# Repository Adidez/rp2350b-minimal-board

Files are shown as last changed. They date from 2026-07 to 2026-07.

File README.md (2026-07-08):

# RP2350B Minimal Board — AI-Assisted, Gate-Verified KiCad Project

A Raspberry Pi **RP2350B (QFN-80)** minimal development board, taken from the official reference
design to a **fab-ready, evidence-verified state** by a gated, evidence-first hardware pipeline
with a human decision at every gate.

| | |
|---|---|
| MCU | RP2350B, QFN-80 10×10 mm (order **A4 stepping only** — E9 erratum fixed in A4) |
| Board | 52.6 × 72.1 mm, 2-layer, all 48 GPIOs broken out (8 ADC-capable) |
| Design state | Schematic **ERC: 0 errors** · PCB **DRC: 0 errors**, 73/73 nets connected |
| EDA | KiCad 10.0.4 (design migrated from the official KiCad 7 files, equivalence-proven) |

**Top view** — [checks/pcb_top.png](checks/pcb_top.png) · **Bottom** — [checks/pcb_bottom.png](checks/pcb_bottom.png) · **Schematic PDF** — [checks/schematic_review.pdf](checks/schematic_review.pdf)

## Open the design in KiCad

Two ways:
1. **No git needed**: download [RP2350B_minimal_kicad_project.zip](RP2350B_minimal_kicad_project.zip)
   (or the repo ZIP via *Code ▾ → Download ZIP*), unzip, then double-click
   `design/RP2350_80QFN_minimal.kicad_pro`.
2. `git clone https://github.com/Adidez/rp2350b-minimal-board && open design/RP2350_80QFN_minimal.kicad_pro`

Requires **KiCad 9 or 10** (files are v10 format; project-local symbol + footprint libraries and
the STEP model are included, so it opens fully self-contained — no library setup needed).

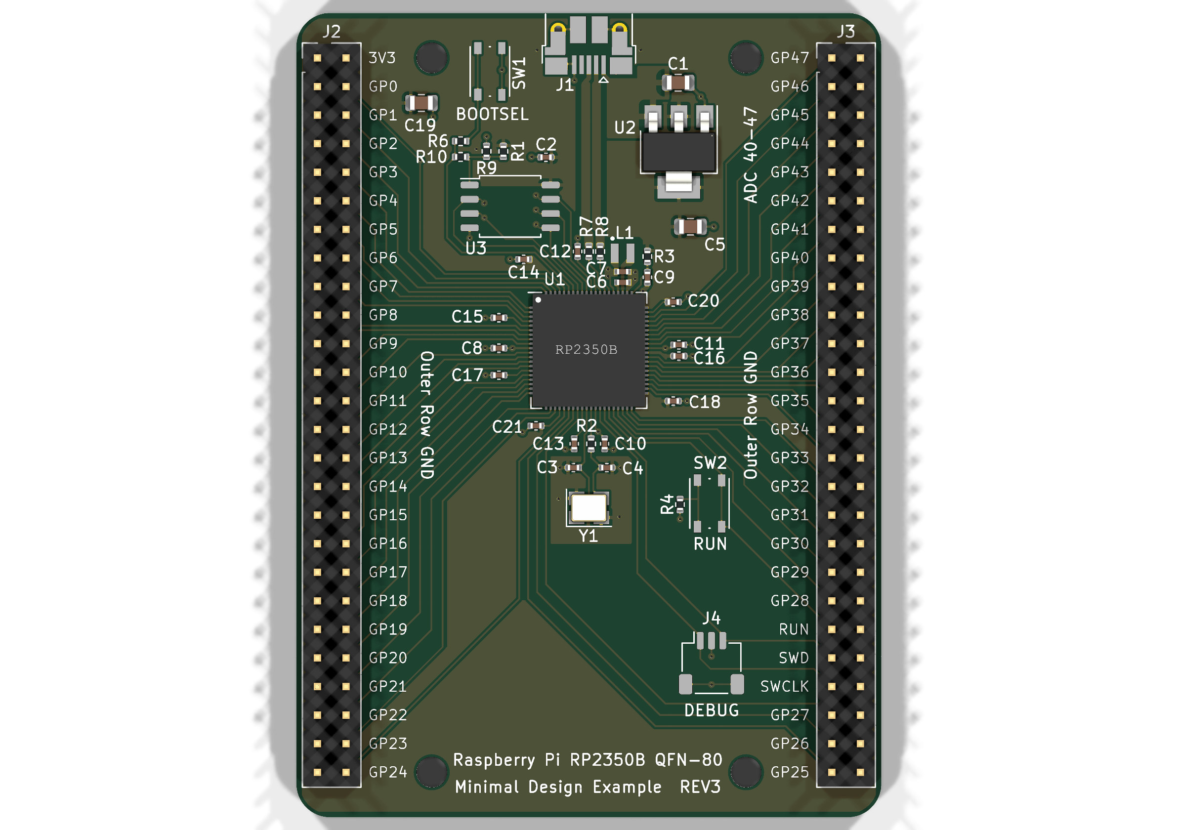
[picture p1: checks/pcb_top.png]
Top render


## What was actually done (the story)

1. **Stage 0 — Baseline.** Copied the official RP2350B minimal reference (KiCad 7) and migrated
   it under KiCad 10: installed global library tables (117 of 193 findings were phantom config
   noise), added the two missing `PWR_FLAG` declarations on the internal-VREG rails
   (`+1V1`, `VREG_AVDD`) that took ERC from 2 errors → 0, and re-linked a footprint KiCad 10
   renamed. Every schematic edit was proven by **netlist equivalence** — 75/75 nets,
   membership byte-identical.
2. **Stage 1 — Sourcing.** All 39 fitted parts got `MPN` + `LCSC` properties (hidden fields —
   the drawing stays clean) and a per-part datasheet corpus. Live-stock-checked ordering table:
   [checks/G1_gate_report.md](checks/G1_gate_report.md). One engineered substitution
   (Würth button → ALPS SKRPACE010, land-pattern-verified). 9 of 17 lines are JLCPCB Basic tier.
3. **Stage 2/3 — Layout verification.** The official routing was independently re-verified under
   modern checkers: 0 electrical DRC findings, full connectivity (511 segments / 48 vias /
   332 pads), USB pair geometry sound for full-speed, solid bottom GND plane. A false-positive
   severity policy from the KiCad-7 project file was fixed at root cause.
   Evidence: [checks/G3_prevalidation.md](checks/G3_prevalidation.md).
4. **Stage 4 — Fab package: DONE (Gate G4 PASS).** [fab/](fab/) holds the upload-ready set:
   [gerber zip](fab/RP2350B_minimal_gerbers.zip) (7 Protel-ext layers + PTH/NPTH drills,
   drill-count reconciled exactly against the design), [BOM](fab/bom_jlcpcb.csv) (17 lines,
   100% LCSC-resolved), [CPL](fab/cpl_jlcpcb.csv) (39 parts) and
   [ROTATION_NOTES.md](fab/ROTATION_NOTES.md). Release-gate evidence:
   [checks/G4_fab_release_gate.txt](checks/G4_fab_release_gate.txt).

Full audit trail: `git log` — every gate closes with its own commit and report in [checks/](checks/).

## Repository map

```
design/       The working KiCad project (schematic + routed PCB) — ERC/DRC clean
reference/    Official Raspberry Pi minimal design (untouched) + hardware design guide PDF
checks/       Gate reports + ERC/DRC JSON evidence + renders (the generated documents)
datasheets/   Per-MPN vendor datasheets (17) + manifest
fab/          JLCPCB-ready package: gerber zip, assembly BOM (LCSC), CPL, rotation notes
.claude/      The pipeline skill: stage gates, RP2350B design rules, toolchain quirks
```

## The design rules that matter (and that generic AI gets wrong)

- **A4 stepping only** (`RP2350B0A4`, LCSC C9900208890): A2 has erratum E9 (GPIO input-mode
  leakage ~120 µA, latches ~2.2 V). Verify at bring-up via `rp2350_chip_version()`.
- The RP2350 core regulator is a **switcher, not an LDO**: the 3.3 µH inductor
  (Abracon AOTA-B201610S3R3, **polarity dot**) is mandatory.
- `QSPI_SS` is the BOOTSEL strap and `QSPI SD1` selects the bootloader interface — neither may
  be loaded or biased at reset.
- Crystal is CL=10 pF (ABM8-272-T3) with tuned damping — don't substitute a 20 pF part without
  re-deriving load caps.
- Full list with sources: [.claude/skills/rp2350b-hardware-pipeline/references/rp2350b-design-rules.md](.claude/skills/rp2350b-hardware-pipeline/references/rp2350b-design-rules.md)

## Reproduce the verification yourself

```bash
KCLI=/Applications/KiCad/KiCad.app/Contents/MacOS/kicad-cli   # macOS bundle path
$KCLI sch erc --severity-all --output /tmp/erc.rpt design/RP2350_80QFN_minimal.kicad_sch   # → 0 errors
$KCLI pcb drc --severity-all --refill-zones --output /tmp/drc.rpt design/RP2350_80QFN_minimal.kicad_pcb  # → 0 errors
$KCLI pcb render --side top --output /tmp/top.png design/RP2350_80QFN_minimal.kicad_pcb
```

Expected residual warnings are documented (66 `endpoint_off_grid` + 6 `lib_symbol_mismatch` on
the schematic; 52 metadata findings on the PCB) — see the gate reports for the keep-rationale.

## Remaining path to a live board (human steps)

1. **Order at JLCPCB**: upload [fab/RP2350B_minimal_gerbers.zip](fab/RP2350B_minimal_gerbers.zip) +
   [BOM](fab/bom_jlcpcb.csv) + [CPL](fab/cpl_jlcpcb.csv). In the assembly preview, verify
   orientation of U1/U2/U3/J1/L1/Y1 against [checks/pcb_top.png](checks/pcb_top.png) — see
   [fab/ROTATION_NOTES.md](fab/ROTATION_NOTES.md). RP2350B **A4** (C9900208890) is a
   global-sourcing part — reserve early; re-verify all Extended-tier stock (table dated
   2026-07-07). Pick **Standard** assembly if J2/J3 headers should be machine-placed
   (Economic = SMD-only → hand-solder the headers).
2. **Bring-up**: 3V3 → 1V1 (proves VREG + inductor) → hold BOOTSEL, plug USB → mass-storage
   enumeration → flash a UF2 → confirm **A4** in silicon via `rp2350_chip_version()`.

## Attribution & licenses

- Base design: **Raspberry Pi Ltd** — "RP2350B QFN80 Minimal Design Example" from
  [Hardware design with RP2350](https://datasheets.raspberrypi.com/rp2350/hardware-design-with-rp2350.pdf)
  (© Raspberry Pi Ltd, redistributed with attribution; reference copy unmodified in `reference/`).
- Vendor datasheets in `datasheets/` remain the property of their respective manufacturers
  (Winbond, onsemi, Abracon, Samsung, UNI-ROYAL, ALPS, JST, Amphenol, XKB, Raspberry Pi).
- Verification tooling: [KiCad](https://kicad.org) 10.0.4 · [kicad-happy](https://github.com/aklofas/kicad-happy)
  (analysis) · [KiCadRoutingTools](https://github.com/drandyhaas/KiCadRoutingTools) (post-route checks).
- Pipeline definition: project-specific gated skill
  ([.claude/skills/rp2350b-hardware-pipeline](.claude/skills/rp2350b-hardware-pipeline)).

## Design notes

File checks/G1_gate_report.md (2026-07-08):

# Gate G1 — PASS (2026-07-07)

Schematic: design/RP2350_80QFN_minimal.kicad_sch @ 452c132.
Independent verify: ERC 0 errors (66 endpoint_off_grid + 6 lib_symbol_mismatch keep-set) ·
39 MPN + 39 LCSC properties · 17 datasheet PDFs + manifest (kicad-happy convention) ·
analyzer: 2 findings total = the known-benign RS-001 pair; DS-001 cleared; netlist membership
75/75 unchanged (agent-verified, s-expression compare).

## Ordering table (live stock 2026-07-07 — RE-VERIFY at order time)

| Refs | MPN | LCSC | Tier | Stock seen | Notes |
|---|---|---|---|---|---|
| C1,C5,C19 10u 0805 | CL21A106KAYNNNE | C15850 | Basic | 12.7M | |
| C2,C8,C11–C18,C20,C21 100n | CL05B104KO5NNNC | C1525 | Basic | 54M | |
| C3,C4 15p C0G | 0402CG150J500NT | C1548 | Basic | 882K | crystal loads |
| C6,C7,C9,C10 4.7u | CL05A475MP5NRNC | C23733 | Basic | 4.8M | |
| L1 3.3µH | AOTA-B201610S3R3-101-T | C42411119 | Extended | 22.5K | exact qualified part; POLARITY DOT |
| R2,R4,R6 1k | 0402WGF1001TCE | C11702 | Basic | 12.6M | |
| R3 33 | 0402WGF330JTCE | C25105 | Basic | 4.8M | |
| R7,R8 27 | 0402WGF270JTCE | C25100 | Extended | 273K | USB series; no Basic 27Ω exists |
| R10 0R | 0402WGF0000TCE | C17168 | Basic | 18.4M | |
| Y1 | ABM8-272-T3 | C20625731 | Extended | 15.7K | CL=10pF qualified |
| U1 | RP2350B **A4** | C9900208890 | Extended | 0 shelf — JLC global-sourcing, procured per order | **reserve early**; alt C42415655 rejected (stepping unverified) |
| U2 | NCP1117ST33T3G | C26537 | Extended | 14.2K | |
| U3 | W25Q128JVSIQ | C97521 | Basic | 110K | |
| J1 | 10103594-0001LF | C428495 | Extended | 7.8K | exact Amphenol |
| J2,J3 2×26 | X6521WV-2x26H-C60D30 | C725898 | Extended | **781** | watch stock |
| J4 | SM03B-SRSS-TB(LF)(SN) | C160403 | Extended | 4.5K | SWD |
| SW1,SW2 | **ALPS SKRPACE010** | C139797 | Extended | 156K | **SUBSTITUTION** for Würth 434133025816 (not carried): land pattern verified exact match (1.05×0.65 @ ±2.075/±1.075), same 4.2×3.2 J-bend; 2.55N vs 1.6N actuation |
| H1–H4 | — | — | — | — | mounting holes, no part |

DNF (excluded from order): C22, R1, R9, R11, R13, U4.

## Datasheet corrections made
- W25Q128JVSIQ: schematic's legacy URL pointed at the JV_DTR family doc — corrected to plain JV.
- NCP1117: onsemi direct blocked → LCSC CDN copy, manifest patched.

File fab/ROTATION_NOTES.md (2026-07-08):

# CPL Rotation Notes — JLCPCB upload preview (MANDATORY human check)

Generated with Stage 4 fab package (Gate G4), 2026-07-07.
Source: `fab/cpl_jlcpcb.csv` (kicad-cli pos export, front side, mm, rotations
normalized 0–360). **No rotation offsets were pre-applied.**

## Why no offsets were baked in

Per the kicad-happy `jlcpcb` skill guidance: JLCPCB's pick-and-place uses
different rotation conventions than KiCad for some footprint families, but
JLCPCB also maintains its own per-LCSC-part orientation database and its
order-review step renders every part on the board. Blindly adding the
"typical" offsets on top of that database risks double-rotation. This is our
**first assembly order** of this board — the skill's process is: verify in
the upload preview now, then record any corrections needed and apply them to
future CPL exports.

**At upload time: open the JLCPCB assembly preview and visually confirm pin-1
/ polarity of every part below against `checks/pcb_top.png` (approved 3D
render) before paying.**

## Parts to eyeball, with expected-offset hints (from the jlcpcb skill table)

| Ref | Package | CPL rotation | Skill's typical JLCPCB offset | What to check in preview |
|-----|---|---|---|---|
| U1 | QFN-80 (RP2350B) | 0.0 | QFN: +90° | Pin-1 dot top-left when text upright; 0.4 mm pitch — any rotation error is fatal |
| U2 | SOT-223 (NCP1117) | 270.0 | SOT-223: +180° | Tab (pin 2/Vout) toward board edge as in render |
| U3 | SOIC-8 (W25Q128JVS) | 0.0 | SOIC-8: +90° or +270° | Pin-1 dot orientation vs silkscreen dot |
| J1 | USB Micro-B (Amphenol 10103594-0001LF) | 180.0 | USB connectors: varies | Receptacle opening must face off-board edge |
| L1 | L_pol_2016 (AOTA-B201610S3R3-101-T) | 0.0 | not in table — **polarized inductor** | **POLARITY DOT** must match reference layout (G1 note); VREG switcher inductor |
| Y1 | Crystal 3225 4-pin (ABM8-272-T3) | 0.0 | not in table | Pin-1 corner vs footprint; 4-pad crystal shorts GND if rotated 90° |

Lower-risk but glance anyway: SW1/SW2 (270/90), J4 (JST SH, 0.0) — connector
keying visible in preview; passives are symmetric.

## Other CPL conventions

- Coordinates are KiCad pos-file convention (absolute board origin, Y
  negative-down); JLCPCB auto-aligns the CPL to the gerbers in its preview —
  if parts land off-board in the preview, use JLCPCB's "align" tools, do not
  hand-edit coordinates.
- J2/J3 (2×26 0.100" headers) are through-hole: they appear in BOM+CPL for
  Standard (THT-capable) assembly; delete both lines from BOM+CPL instead if
  ordering Economic/SMD-only and hand-soldering the headers.
- After this first order: record every correction JLCPCB's preview required
  into this file and pre-apply them in the next CPL export (skill guidance).

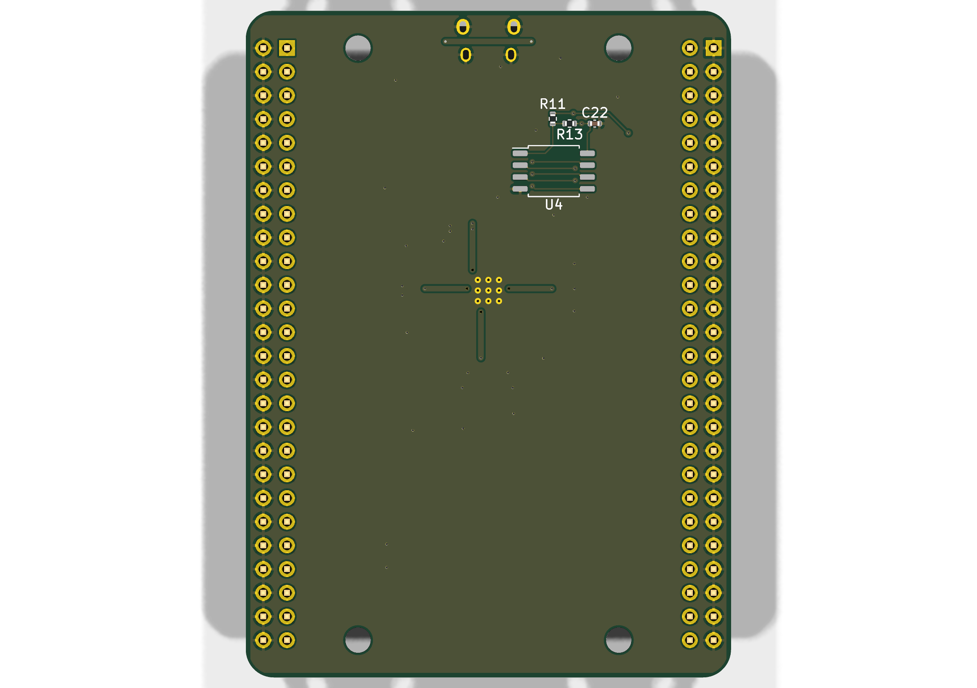
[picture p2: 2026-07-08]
checks/pcb_bottom.png

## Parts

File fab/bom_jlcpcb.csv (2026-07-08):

Comment | Designator | Footprint | LCSC Part #
10u | C1,C5,C19 | C_0805_2012Metric | C15850
100n | C2,C8,C11,C12,C13,C14,C15,C16,C17,C18,C20,C21 | C_0402_1005Metric | C1525
15p | C3,C4 | C_0402_1005Metric | C1548
4.7u | C6,C7,C9,C10 | C_0402_1005Metric | C23733
USB_B_Micro | J1 | USB_Micro-B_Amphenol_10103594-0001LF_Horizontal | C428495
Conn_02x26_Odd_Even | J2,J3 | PinHeader_2x26_P2.54mm_Vertical | C725898
SM03B-SRSS-TB | J4 | JST_SH_SM03B-SRSS-TB_1x03-1MP_P1.00mm_Horizontal | C160403
3.3u | L1 | L_pol_2016 | C42411119
1k | R2,R4,R6 | R_0402_1005Metric | C11702
33 | R3 | R_0402_1005Metric | C25105
27 | R7,R8 | R_0402_1005Metric | C25100
0 | R10 | R_0402_1005Metric | C17168
SW_Push | SW1,SW2 | SW_Push_1P1T_NO_Vertical_Wuerth_434133025816 | C139797
RP2350_80QFN | U1 | RP2350-QFN-80-1EP_10x10_P0.4mm_EP3.4x3.4mm_ThermalVias | C9900208890
NCP1117-3.3_SOT223 | U2 | SOT-223-3_TabPin2 | C26537
W25Q128JVS | U3 | SOIC-8_5.3x5.3mm_P1.27mm | C97521
ABM8-272-T3 | Y1 | Crystal_SMD_3225-4Pin_3.2x2.5mm | C20625731

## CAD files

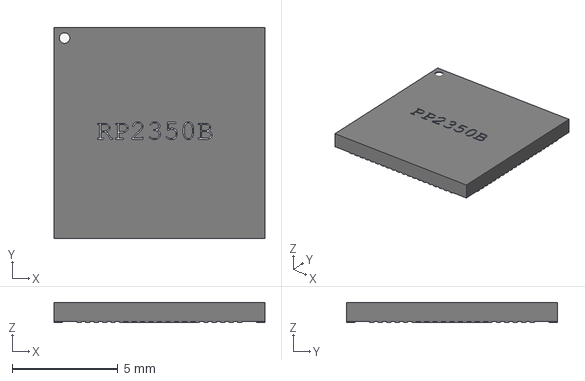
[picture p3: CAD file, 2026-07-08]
design/RP2350_QFN80.step
10.0 x 10.0 x 0.95 mm

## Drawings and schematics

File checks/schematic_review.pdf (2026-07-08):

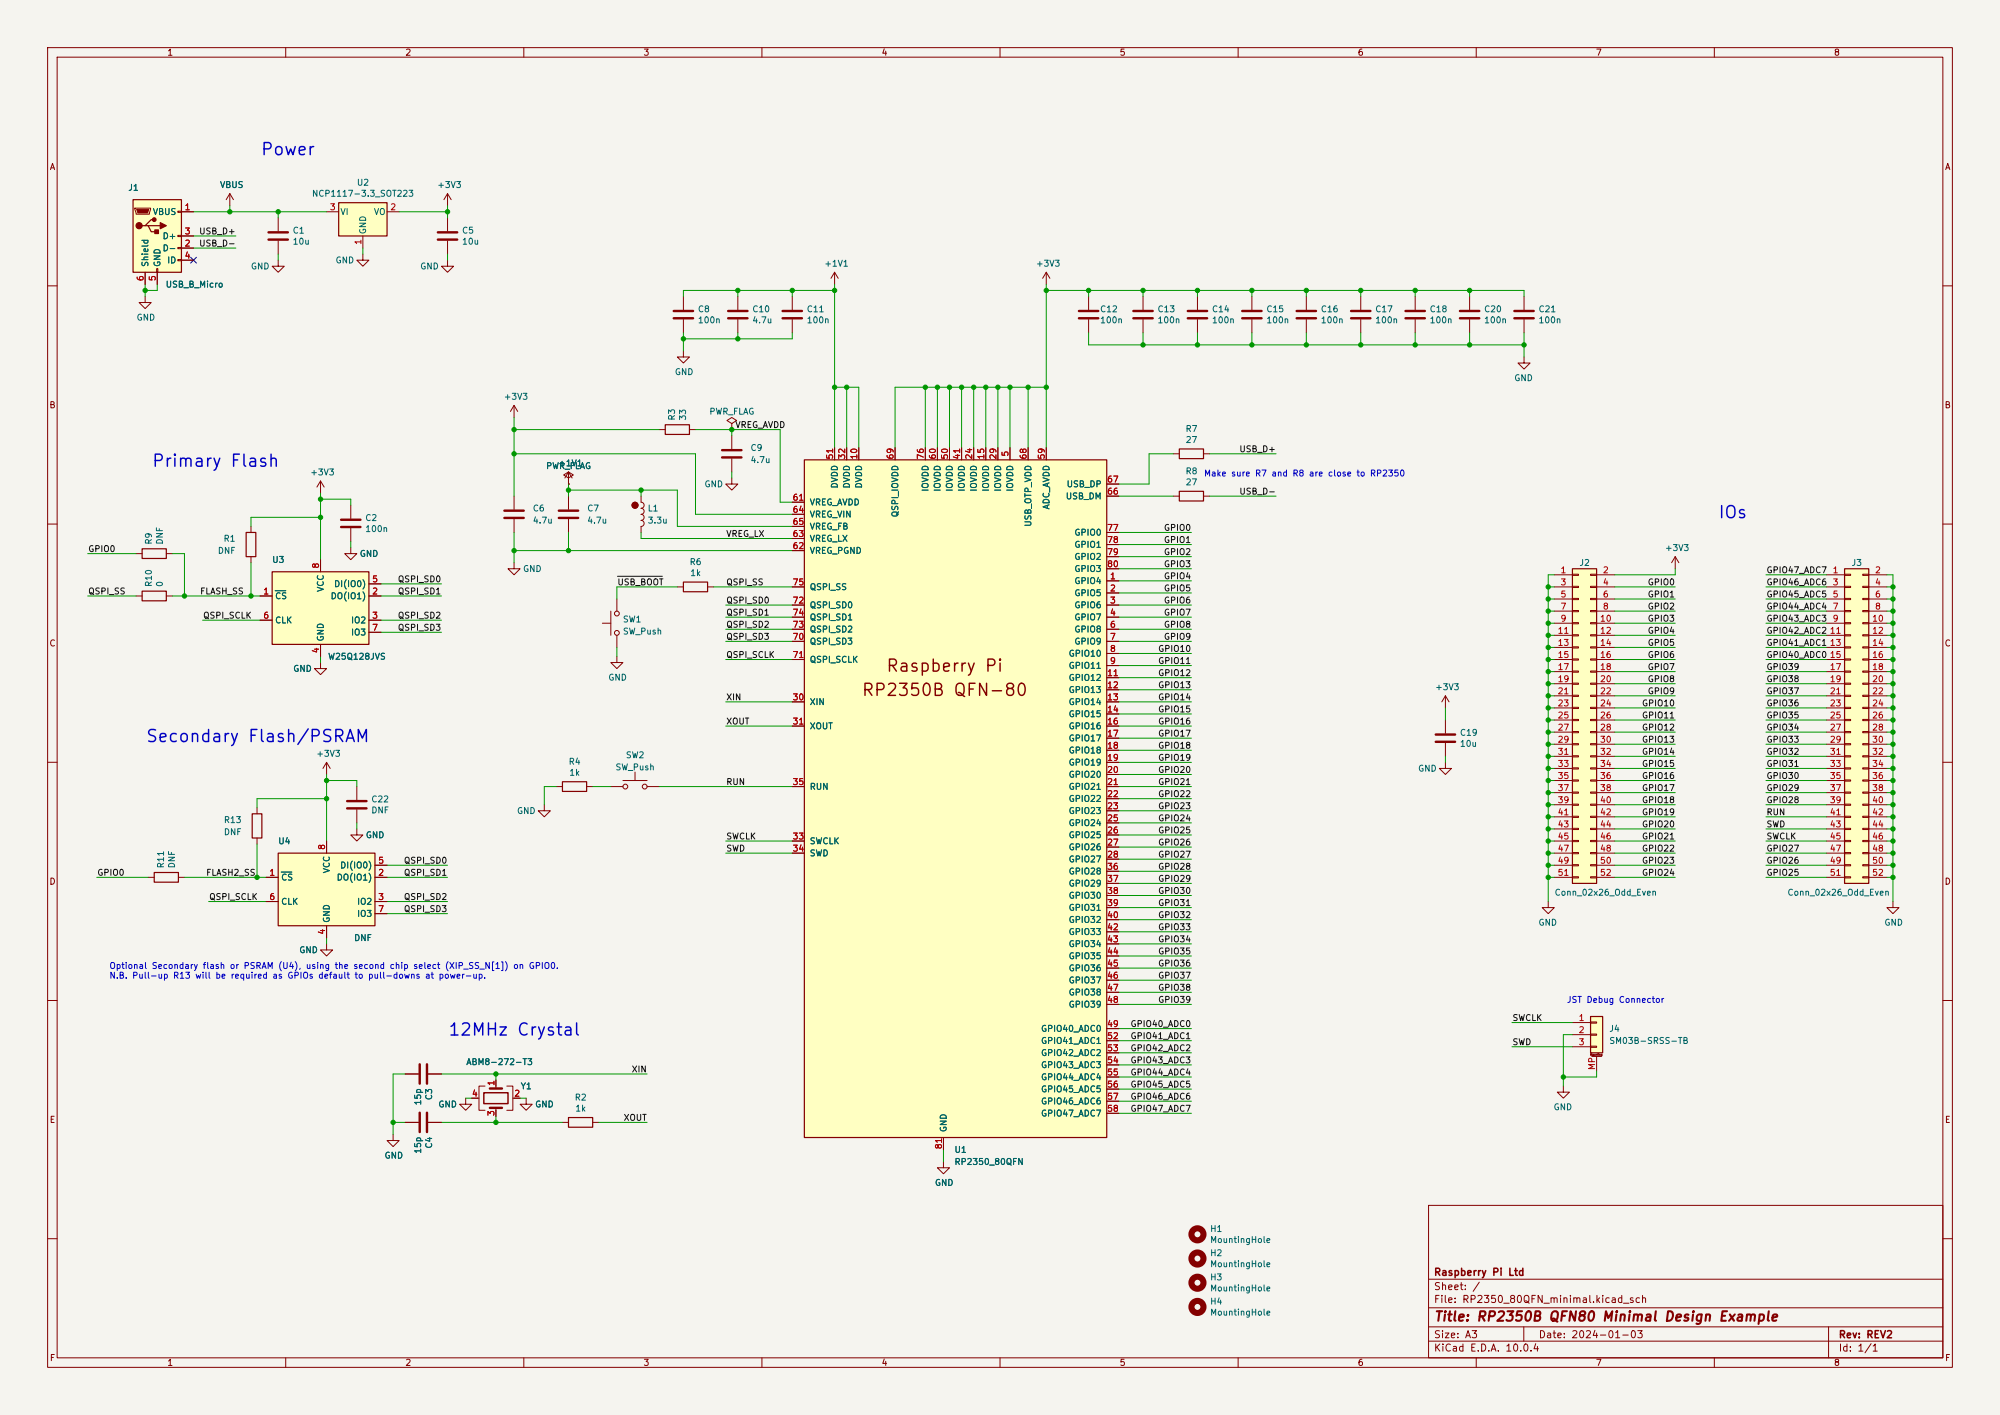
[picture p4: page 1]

5 GPIO8 6 GPIO9 7 GPIO10 8 GPIO11 9 DVDD 10 GPIO12 11 GPIO13 12 GPIO14 13 GPIO15 14 IOVDD 15 GPIO16 16 GPIO17 17 GPIO18 18 GPIO19 19 GPIO20 20 GPIO21 21 GPIO22 22 GPIO23 23 IOVDD 24 GPIO24 25 GPIO25 26 GPIO26 27 GPIO27 28 IOVDD 29

Make sure R7 and R8 are close to RP2350

Optional Secondary flash or PSRAM (U4), using the second chip select (XIP_SS_N[1]) on GPIO0. N.B. Pull-up R13 will be required as GPIOs default to pull-downs at power-up. Secondary Flash/PSRAM

8U4 DNF GND R11 DNF +3V3 GND

Raspberry Pi Ltd
Sheet: /
File: RP2350_80QFN_minimal.kicad_sch
Title: RP2350B QFN80 Minimal Design Example

Size: A3 | Rev: REV2 | F Date: 2024-01-03
KiCad E.D.A. 10.0.4 | Id: 1/1

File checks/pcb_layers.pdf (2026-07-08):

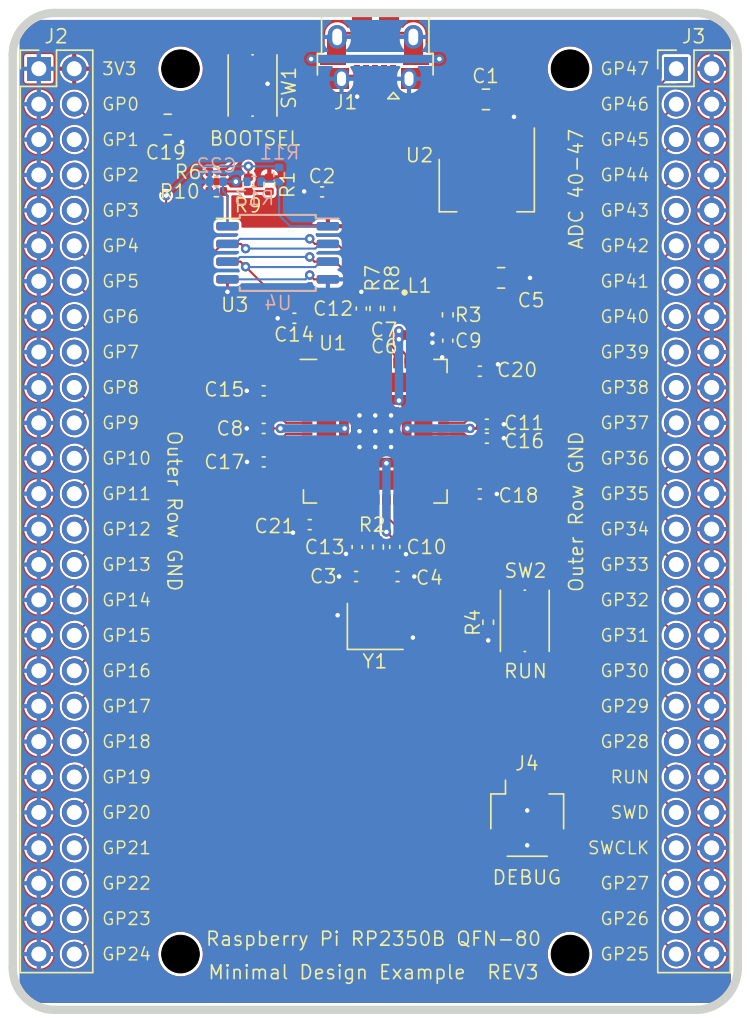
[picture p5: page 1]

DEBUG ADC 40-47 Outer Row GND Outer Row GND
GP27 GP26 GP25 BOOTSEL Raspberry Pi RP2350B QFN-80 Minimal Design Example REV3 RUN

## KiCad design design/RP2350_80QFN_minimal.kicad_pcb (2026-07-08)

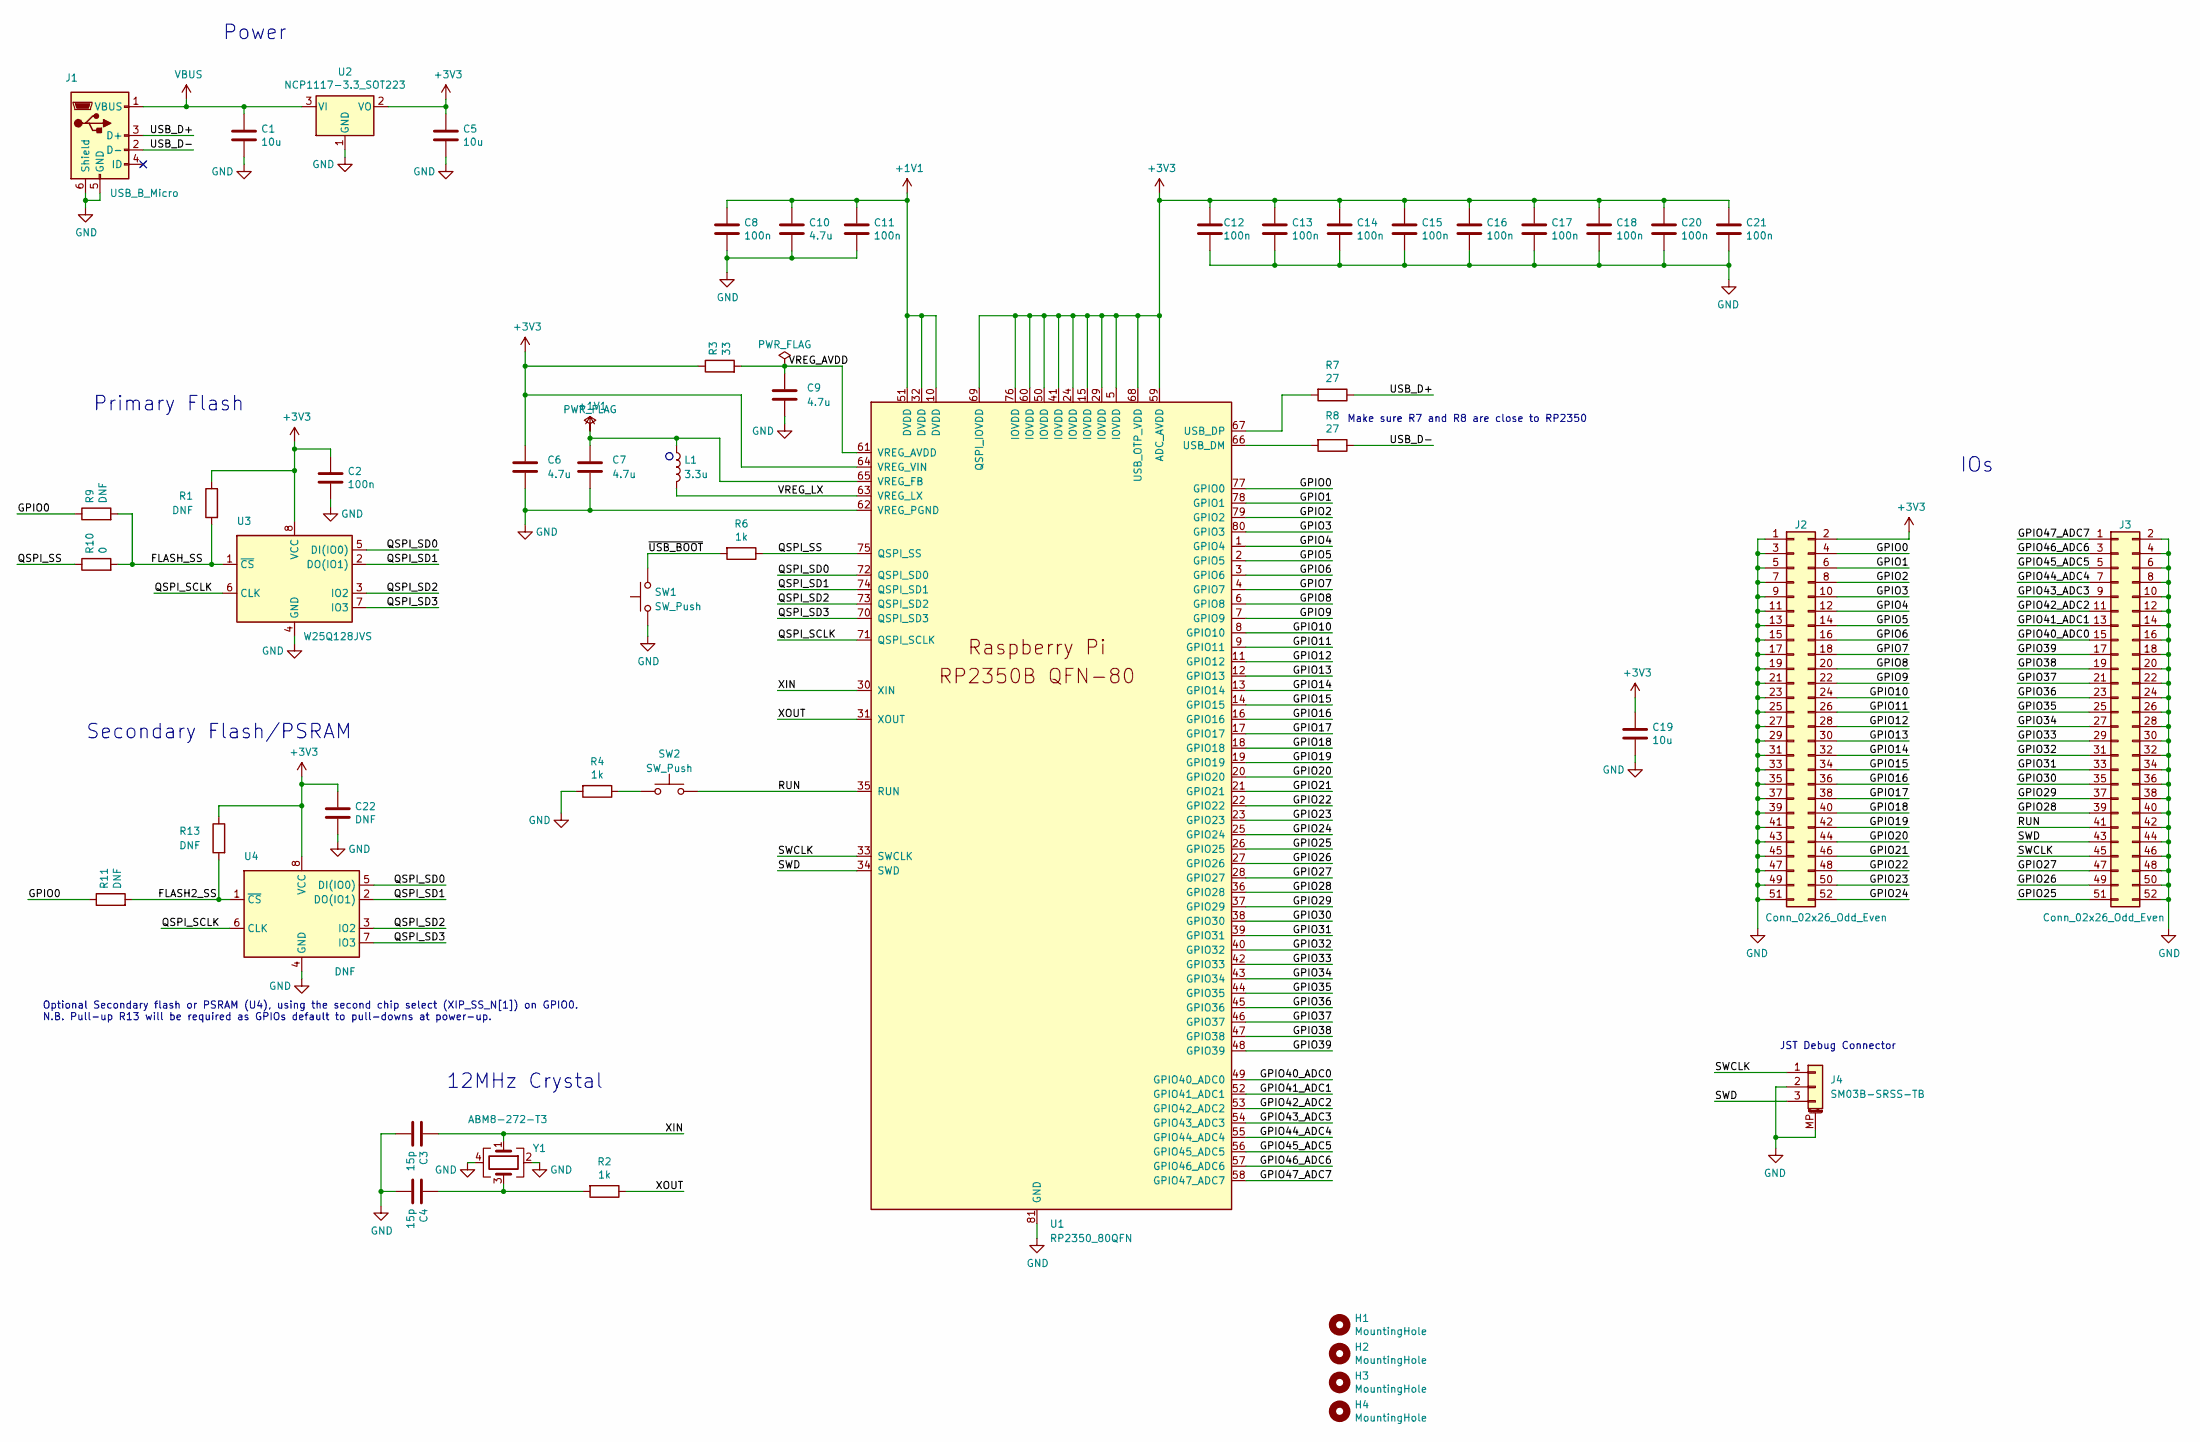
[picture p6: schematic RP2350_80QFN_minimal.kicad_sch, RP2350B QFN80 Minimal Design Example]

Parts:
C1, C5, C19: 10u; C_0805_2012Metric; MPN CL21A106KAYNNNE; LCSC C15850
C2, C8, C11, C12, C13, C14, C15, C16, C17, C18, C20, C21: 100n; C_0402_1005Metric; MPN CL05B104KO5NNNC; LCSC C1525
C3, C4: 15p; C_0402_1005Metric; MPN 0402CG150J500NT; LCSC C1548
C6, C7: 4.7u; C_0402_1005Metric_small_pads; MPN CL05A475MP5NRNC; LCSC C23733
C9, C10: 4.7u; C_0402_1005Metric; MPN CL05A475MP5NRNC; LCSC C23733
C22: DNF; C_0402_1005Metric
H1, H2, H3, H4: MountingHole; MountingHole_2.7mm_M2.5
J1: USB_B_Micro; USB_Micro-B_Amphenol_10103594-0001LF_Horizontal; MPN 10103594-0001LF; LCSC C428495
J2, J3: Conn_02x26_Odd_Even; PinHeader_2x26_P2.54mm_Vertical; MPN X6521WV-2x26H-C60D30; LCSC C725898
J4: SM03B-SRSS-TB; JST_SH_SM03B-SRSS-TB_1x03-1MP_P1.00mm_Horizontal; MPN SM03B-SRSS-TB(LF)(SN); LCSC C160403
L1: 3.3u; L_pol_2016; MPN AOTA-B201610S3R3-101-T; LCSC C42411119
R1, R9, R11, R13: DNF; R_0402_1005Metric
R2, R4, R6: 1k; R_0402_1005Metric; MPN 0402WGF1001TCE; LCSC C11702
R3: 33; R_0402_1005Metric; MPN 0402WGF330JTCE; LCSC C25105
R7, R8: 27; R_0402_1005Metric; MPN 0402WGF270JTCE; LCSC C25100
R10: 0; R_0402_1005Metric; MPN 0402WGF0000TCE; LCSC C17168
SW1, SW2: SW_Push; SW_Push_1P1T_NO_Vertical_Wuerth_434133025816; MPN SKRPACE010; LCSC C139797
U1: RP2350_80QFN; RP2350-QFN-80-1EP_10x10_P0.4mm_EP3.4x3.4mm_ThermalVias; MPN RP2350B A4; LCSC C9900208890
U2: NCP1117-3.3_SOT223; SOT-223-3_TabPin2; MPN NCP1117ST33T3G; LCSC C26537
U3: W25Q128JVS; SOIC-8_5.3x5.3mm_P1.27mm; MPN W25Q128JVSIQ; LCSC C97521
U4: DNF; SOIC-8_5.3x5.3mm_P1.27mm
Y1: ABM8-272-T3; Crystal_SMD_3225-4Pin_3.2x2.5mm; MPN ABM8-272-T3; LCSC C20625731

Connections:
+1V1: C7.1, C8.1, C10.1, C11.1, L1.1, U1.10 (DVDD), U1.32 (DVDD), U1.51 (DVDD), U1.65 (VREG_FB)
+3V3: C2.1, C5.1, C6.1, C12.1, C13.1, C14.1, C15.1, C16.1, C17.1, C18.1, C19.1, C20.1, C21.1, C22.1, J2.2, R1.1, R3.1, R13.1, U1.5 (IOVDD), U1.15 (IOVDD), U1.24 (IOVDD), U1.29 (IOVDD), U1.41 (IOVDD), U1.50 (IOVDD), U1.59 (ADC_AVDD), U1.60 (IOVDD), U1.64 (VREG_VIN), U1.68 (USB_OTP_VDD), U1.69 (QSPI_IOVDD), U1.76 (IOVDD), U2.2 (VO), U3.8 (VCC), U4.8 (VCC)
/FLASH2_SS: R11.2, R13.2, U4.1 (~CS)
/FLASH_SS: R1.2, R9.2, R10.2, U3.1 (~CS)
/GPIO0: J2.4, R9.1, R11.1, U1.77 (GPIO0)
/GPIO1: J2.6, U1.78 (GPIO1)
/GPIO2: J2.8, U1.79 (GPIO2)
/GPIO3: J2.10, U1.80 (GPIO3)
/GPIO4: J2.12, U1.1 (GPIO4)
/GPIO5: J2.14, U1.2 (GPIO5)
/GPIO6: J2.16, U1.3 (GPIO6)
/GPIO7: J2.18, U1.4 (GPIO7)
/GPIO8: J2.20, U1.6 (GPIO8)
/GPIO9: J2.22, U1.7 (GPIO9)
/GPIO10: J2.24, U1.8 (GPIO10)
/GPIO11: J2.26, U1.9 (GPIO11)
/GPIO12: J2.28, U1.11 (GPIO12)
/GPIO13: J2.30, U1.12 (GPIO13)
/GPIO14: J2.32, U1.13 (GPIO14)
/GPIO15: J2.34, U1.14 (GPIO15)
/GPIO16: J2.36, U1.16 (GPIO16)
/GPIO17: J2.38, U1.17 (GPIO17)
/GPIO18: J2.40, U1.18 (GPIO18)
/GPIO19: J2.42, U1.19 (GPIO19)
/GPIO20: J2.44, U1.20 (GPIO20)
/GPIO21: J2.46, U1.21 (GPIO21)
/GPIO22: J2.48, U1.22 (GPIO22)
/GPIO23: J2.50, U1.23 (GPIO23)
/GPIO24: J2.52, U1.25 (GPIO24)
/GPIO25: J3.51, U1.26 (GPIO25)
/GPIO26: J3.49, U1.27 (GPIO26)
/GPIO27: J3.47, U1.28 (GPIO27)
/GPIO28: J3.39, U1.36 (GPIO28)
/GPIO29: J3.37, U1.37 (GPIO29)
/GPIO30: J3.35, U1.38 (GPIO30)
/GPIO31: J3.33, U1.39 (GPIO31)
/GPIO32: J3.31, U1.40 (GPIO32)
/GPIO33: J3.29, U1.42 (GPIO33)
/GPIO34: J3.27, U1.43 (GPIO34)
/GPIO35: J3.25, U1.44 (GPIO35)
/GPIO36: J3.23, U1.45 (GPIO36)
/GPIO37: J3.21, U1.46 (GPIO37)
/GPIO38: J3.19, U1.47 (GPIO38)
/GPIO39: J3.17, U1.48 (GPIO39)
/GPIO40_ADC0: J3.15, U1.49 (GPIO40_ADC0)
/GPIO41_ADC1: J3.13, U1.52 (GPIO41_ADC1)
/GPIO42_ADC2: J3.11, U1.53 (GPIO42_ADC2)
/GPIO43_ADC3: J3.9, U1.54 (GPIO43_ADC3)
/GPIO44_ADC4: J3.7, U1.55 (GPIO44_ADC4)
/GPIO45_ADC5: J3.5, U1.56 (GPIO45_ADC5)
/GPIO46_ADC6: J3.3, U1.57 (GPIO46_ADC6)
/GPIO47_ADC7: J3.1, U1.58 (GPIO47_ADC7)
/QSPI_SCLK: U1.71 (QSPI_SCLK), U3.6 (CLK), U4.6 (CLK)
/QSPI_SD0: U1.72 (QSPI_SD0), U3.5 (DI(IO0)), U4.5 (DI(IO0))
/QSPI_SD1: U1.74 (QSPI_SD1), U3.2 (DO(IO1)), U4.2 (DO(IO1))
/QSPI_SD2: U1.73 (QSPI_SD2), U3.3 (IO2), U4.3 (IO2)
/QSPI_SD3: U1.70 (QSPI_SD3), U3.7 (IO3), U4.7 (IO3)
/QSPI_SS: R6.1, R10.1, U1.75 (QSPI_SS)
/RUN: J3.41, SW2.2, U1.35 (RUN)
/SWCLK: J3.45, J4.1, U1.33 (SWCLK)
/SWD: J3.43, J4.3, U1.34 (SWD)
/USB_D+: J1.3 (D+), R7.1
/USB_D-: J1.2 (D-), R8.1
/VREG_AVDD: C9.1, R3.2, U1.61 (VREG_AVDD)
/VREG_LX: L1.2, U1.63 (VREG_LX)
/XIN: C3.1, U1.30 (XIN), Y1.1
/XOUT: R2.1, U1.31 (XOUT)
/~USB_BOOT: R6.2, SW1.2
GND: C1.2, C2.2, C3.2, C4.2, C5.2, C6.2, C7.2, C8.2, C9.2, C10.2, C11.2, C12.2, C13.2, C14.2, C15.2, C16.2, C17.2, C18.2, C19.2, C20.2, C21.2, C22.2, J1.5 (GND), J1.6 (Shield), J2.1, J2.3, J2.5, J2.7, J2.9, J2.11, J2.13, J2.15, J2.17, J2.19, J2.21, J2.23, J2.25, J2.27, J2.29, J2.31, J2.33, J2.35, J2.37, J2.39, J2.41, J2.43, J2.45, J2.47, J2.49, J2.51, J3.2, J3.4, J3.6, J3.8, J3.10, J3.12, J3.14, J3.16, J3.18, J3.20, J3.22, J3.24, J3.26, J3.28, J3.30, J3.32, J3.34, J3.36, J3.38, J3.40, J3.42, J3.44, J3.46, J3.48, J3.50, J3.52, J4.2, J4.MP (MountPin), R4.2, SW1.1, U1.62 (VREG_PGND), U1.81 (GND), U2.1 (GND), U3.4 (GND), U4.4 (GND), Y1.2, Y1.4
unnamed: C4.1, R2.2, Y1.3
unnamed: R4.1, SW2.1
unnamed: R8.2, U1.66 (USB_DM)
unnamed: R7.2, U1.67 (USB_DP)
VBUS: C1.1, J1.1 (VBUS), U2.3 (VI)

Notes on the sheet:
Optional Secondary flash or PSRAM (U4), using the second chip select (XIP_SS_N[1]) on GPIO0. N.B. Pull-up R13 will be required as GPIOs default to pull-downs at power-up.
IOs
12MHz Crystal
Primary Flash
JST Debug Connector
Make sure R7 and R8 are close to RP2350
Secondary Flash/PSRAM
Power

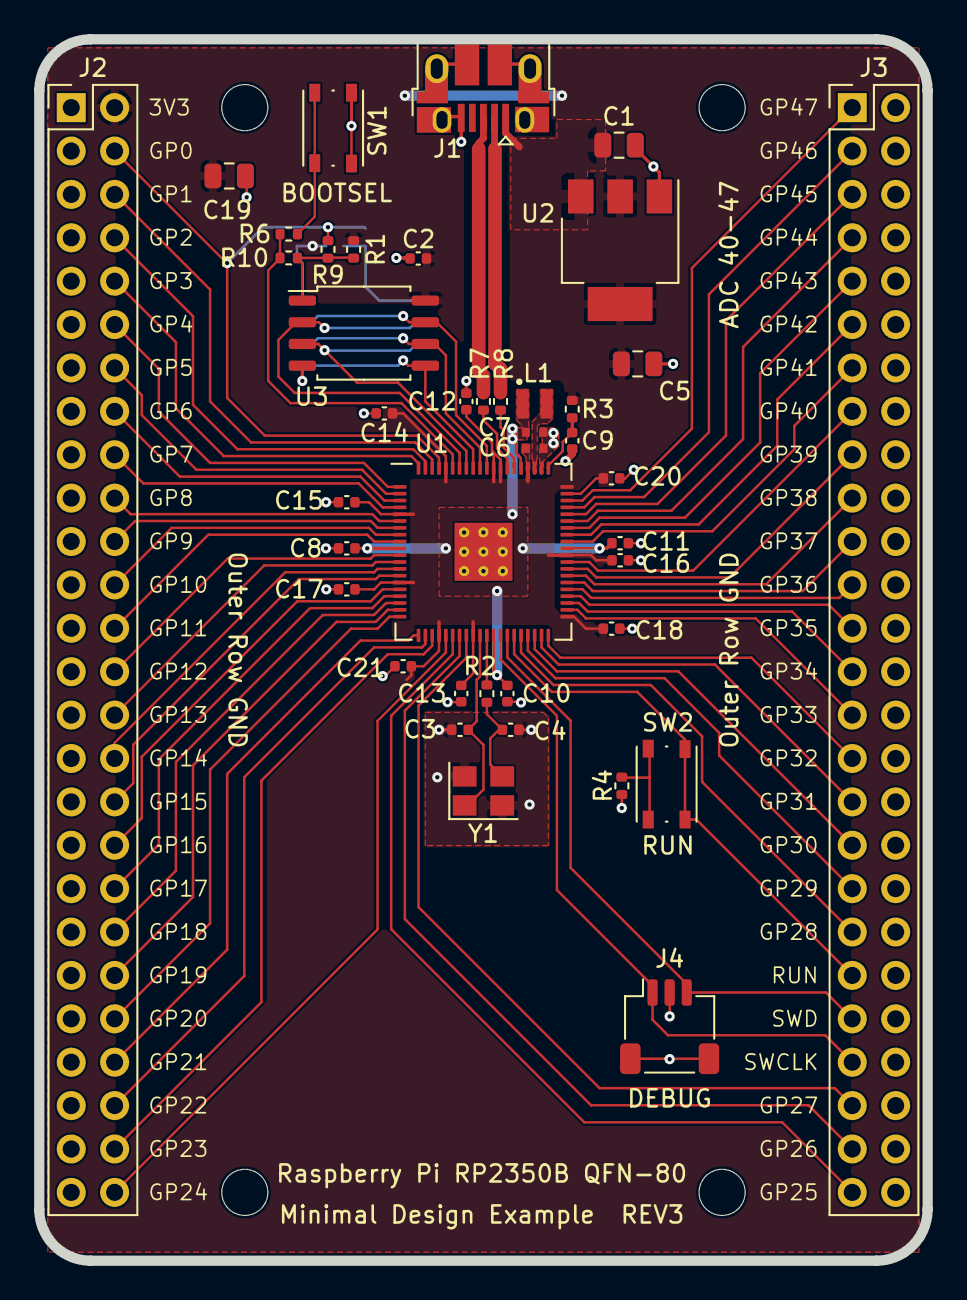
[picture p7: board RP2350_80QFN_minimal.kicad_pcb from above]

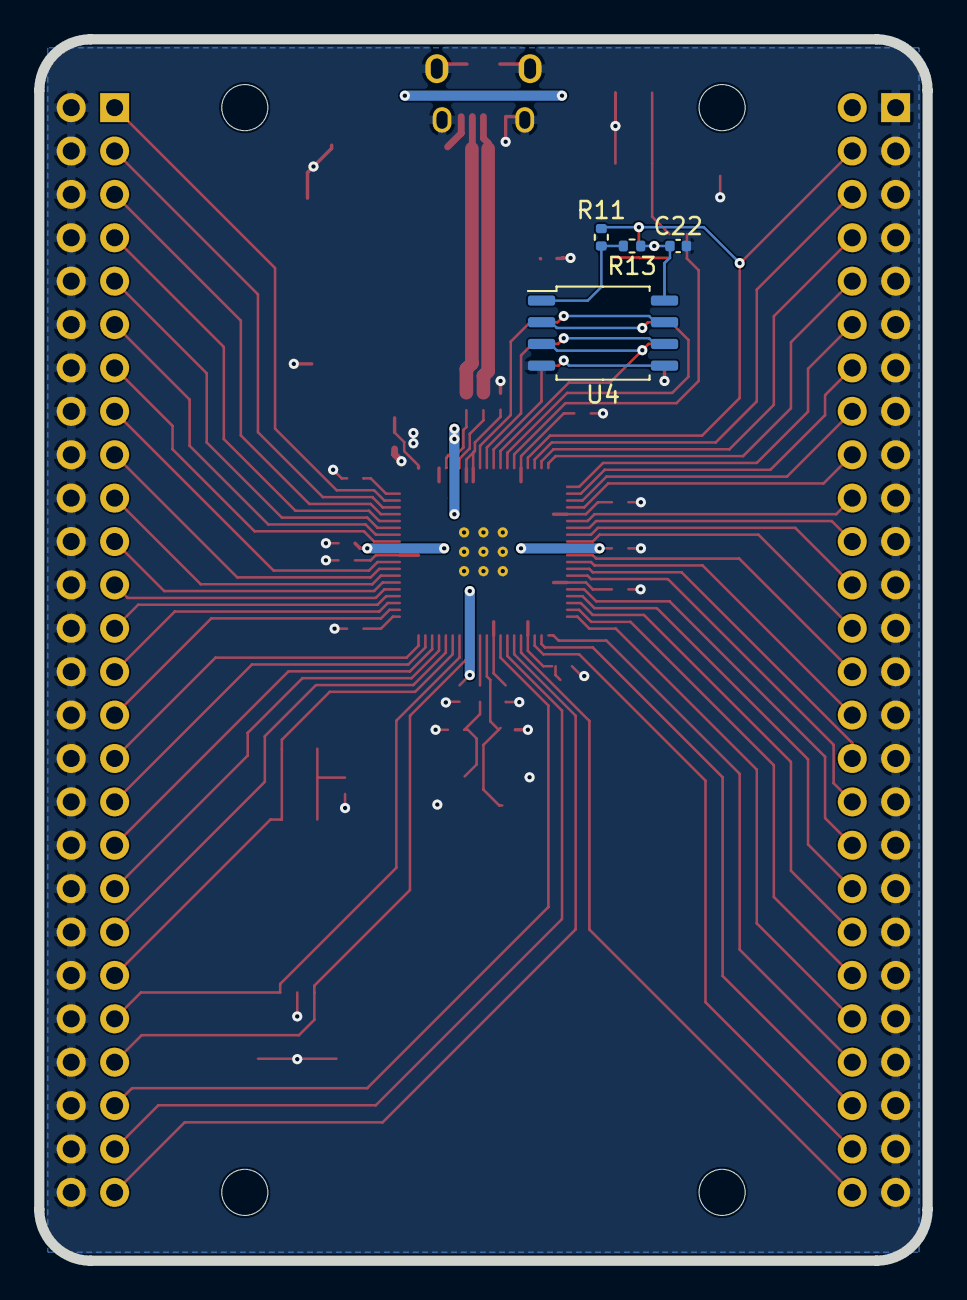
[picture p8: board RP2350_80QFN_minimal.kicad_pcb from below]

Board: 2 copper layers, 52.0 x 71.5 mm, 49 parts (4 on the bottom side), 74 nets.

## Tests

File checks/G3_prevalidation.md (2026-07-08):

# Gate G3 — FINAL: PASS (2026-07-07, post-Stage-2, commit adabefb)

Independent kicad-cli DRC on the v10-converted board (checks/G3_drc.json): **0 errors,
0 unconnected, 0 schematic-parity**; 52 metadata warnings (37 lib_footprint_mismatch keep-embedded,
9 silk_over_copper, 4 silk_overlap, 2 lib_footprint_issues). Routing-tools checkers non-vacuous:
511 segments / 48 vias / 332 pads, 73/73 nets connected, 0 violations. Pad→net equivalence vs
pre-conversion: 332/332 identical. J1/U1 footprint_type_mismatch resolved at ROOT CAUSE: v7
project severity policy → KiCad-10 factory default (ignore); attrs correctly remain SMD for CPL.

---

# Gate G3 Pre-validation — official routing (2026-07-07)

Board: design/RP2350_80QFN_minimal.kicad_pcb (official routing, unmodified). Verdict: **PASS as-is**.

| Check | Tool | Result |
|---|---|---|
| DRC electrical | kicad-cli 10.0.4 --severity-all --refill-zones | 0 electrical (54 metadata/cosmetic only) |
| DRC geometric | check_drc.py @0.15mm (on v10-converted copy) | 0 violations |
| Connectivity | check_connected.py | 73/73 nets (511 segs, 48 vias, 332 pads, 9 zones) |
| Orphan stubs | check_orphan_stubs.py | 11 zone-fed tails (+3V3 ×10, VBUS) — benign, inside own-net pours |
| USB diff pair | geometry analysis | conn side 0.4mm/~0.53mm gap, chip side 0.15mm/~0.23mm; skew 331µm total — fine for USB-FS |
| QSPI/crystal | route-length analysis | QSPI 5.96–26.38mm (10.2mm spread, unmatched — irrelevant at QSPI rates); XIN 11.3mm |
| GND return | zone/segment analysis | full-board B.Cu GND zone; 1 cut under USB (+1V1 jumper, 5mm); QSPI dips carve locally |

## Reference-design quirks — documented, NOT to be "fixed"
- 54 metadata DRC findings incl. J1/U1 footprint-type attribute "errors" (fix attrs in Stage 2 for CPL correctness; rest keep)
- USB pair loosely coupled (~0.5mm gap), not impedance-controlled — normal for FS on the official board
- QSPI unmatched + local B.Cu excursions under itself; +1V1 crosses under USB on B.Cu
- 11 zone-fed stubs; XIN 11.3mm

## Stage-2 obligations discovered
1. Save/convert the PCB to KiCad 10 format during reconcile — REQUIRED for checker validity (see toolchain quirk: v7 tstamp parsing trap)
2. Fix J1/U1 footprint attributes (SMD) — position-file correctness
3. Update-PCB-from-schematic to sync MPN/LCSC fields + U3/U4 footprint rename

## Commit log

2026-07-08 chore: RP2350B project scaffold — stack, pipeline skill, official reference
    [RP2350_80QFN_minimal.kicad_pcb, RP2350_80QFN_minimal.kicad_sch, RP2350_80QFN_minimal.sch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]
2026-07-08 stage0: pristine working copy of RP2350B-minimal reference
    [RP2350_80QFN_minimal.kicad_pcb, RP2350_80QFN_minimal.kicad_sch, RP2350_80QFN_minimal.sch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]
2026-07-08 stage0: PWR_FLAG on +1V1/VREG_AVDD, re-link W25Q128JVS footprint to KiCad10 name
    [RP2350_80QFN_minimal.kicad_sch]
2026-07-08 stage0: Gate G0 PASS — independent ERC verify, kicad-happy report, quirk log, skill+status updates
2026-07-08 stage1: MPN/LCSC population + datasheet corpus (G1 prep)
    [RP2350_80QFN_minimal.kicad_sch]
2026-07-08 stage1: Gate G1 PASS — independent verify, ordering table, G3 prevalidation record, quirk log
2026-07-08 stage2: J1/U1 SMD attributes + KiCad-10 format conversion (pad-net equivalence proven)
    - Board resaved via pcbnew 10.0.4 (v7 tstamp -> v10 uuid format): closes the
    checker-validity trap where kicad_parser saw 0 segments on v7 boards and
    passed vacuously. Checkers now parse 511 segments / 48 vias / 332 pads;
    73/73 nets fully connected; check_drc.py 0 violations.
    - J1/U1 footprint type bits verified/normalized to FP_SMD (bitmask 2 -> 2:
    both were already SMD; non-type attribute bits untouched). SMD is correct
    for Stage-4 position files (SMD-assembled USB connector + QFN).
    - Root cause of the 2 error-severity footprint_type_mismatch findings was NOT
    the attributes: KiCad expects 'Th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
    [RP2350_80QFN_minimal.kicad_pcb]
2026-07-08 stage2/3: Gate G3 PASS final — independent DRC on v10 board, root-cause severity fix documented
2026-07-08 docs: README — project story, gate evidence, design rules, reproduction guide + visual reviews
2026-07-08 chore: session wrap — Stage 4 paused by owner, published-repo pointer, resume instructions
2026-07-08 docs: one-click KiCad project download + open instructions
2026-07-08 stage4: JLCPCB fab package — gerbers/drill/BOM/CPL + release gate
    [bom_jlcpcb.csv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]
2026-07-08 stage4: Gate G4 PASS close-out — fab package documented, ordering path finalized
